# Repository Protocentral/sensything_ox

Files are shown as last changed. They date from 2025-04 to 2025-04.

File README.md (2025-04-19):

Protocentral Sensything Ox Wireless Pulse Sensor Kit based on AFE4400/ESP32S3
========================================
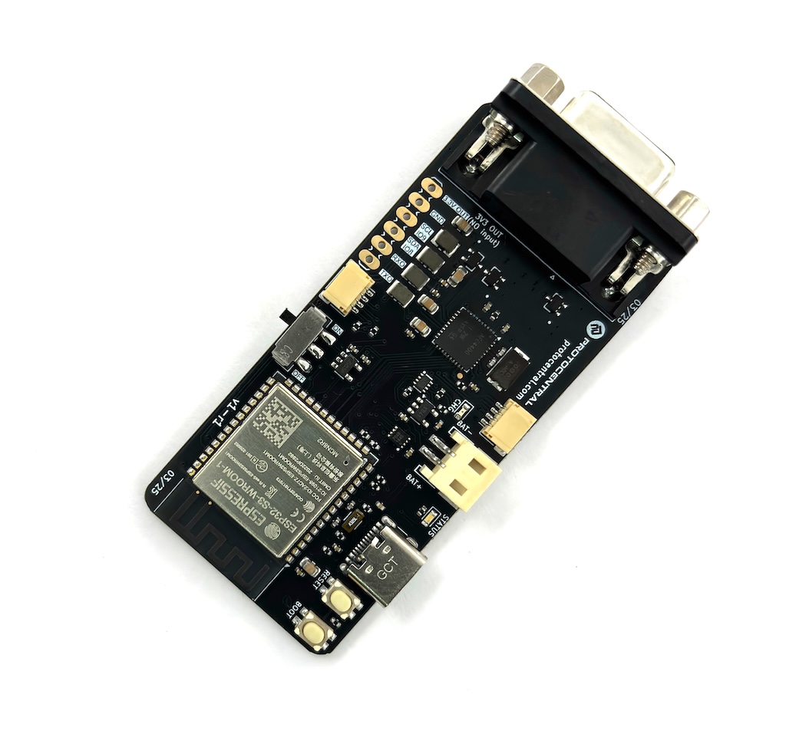
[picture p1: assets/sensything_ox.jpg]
Protocentral Sensything Ox Pulse Oximeter Breakout Board


## Don't have one? [Buy it here](https://protocentral.com/product/protocentral-sensythingox-wireless-pulse-sensor-kit-based-on-afe4400-esp32/)

Protocentral Sensything Ox is the latest, renamed version of our popular [OpenOx](https://github.com/Protocentral/protocentral_openox) Pulse sensor board. It is a standalone, wireless pulse oximetry breakout board that is powered by the ESP32S3 module and uses the AFE4400 IC to measure oxygen levels in the blood while also providing a PPG waveform, heart rate, and SpO2 values measured with high precision.

The Sensything Ox improves upon the previous version of the [OpenOx board](https://github.com/Protocentral/protocentral_openox) by replacing the ESP32 module with the new ESP32S3 with 8MB Flash memory and 2MB PSRAM. This allows for a more powerful and efficient processing of the data collected by the AFE4400 IC. The board is designed to be used in a variety of applications, including medical research, fitness tracking, and remote patient monitoring.

## Hardware Setup

The Sensything Ox programs are all in Arduino and examples are in the examples folder of this repo. To program, select the "ESP32S3 Dev Module" board in the Arduino IDE with the following settings.

* Board: ESP32S3 Dev Module
* USB Mode: Hardware CDC and JTAG
* USB CDC on Boot: Enabled
* Upload Mode: UART0 / Hardware CDC
* PSRAM: QSPI PSRAM

# Documentation

For further details of the board, refer the documentation at the following links:

[Protocentral Sensything Ox Wireless Pulse Sensor Documentation](https://docs.protocentral.com/getting-started-with-openox/)

# Visualizing Output

### USB Streaming

* Open the GUI, make sure to select **AFE4490 breakout** under the **Board** dropdown and the appropriate **Port**. If everything goes well, you will be able to see the screen as pictured above.

   <center>

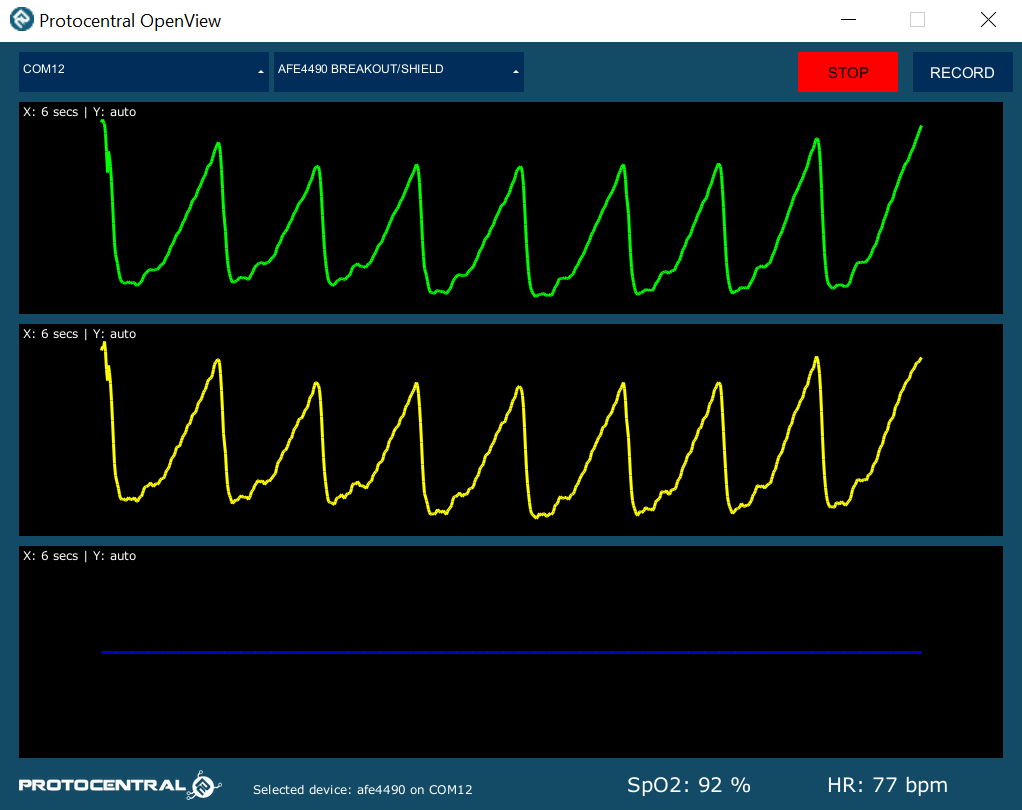
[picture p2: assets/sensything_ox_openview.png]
streaming vitals
  

  </center>

### BLE streaming

 <center>

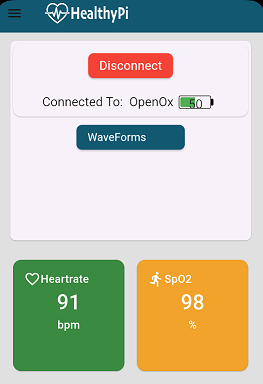
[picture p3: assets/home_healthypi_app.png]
Home
  

  </center>

 <center>

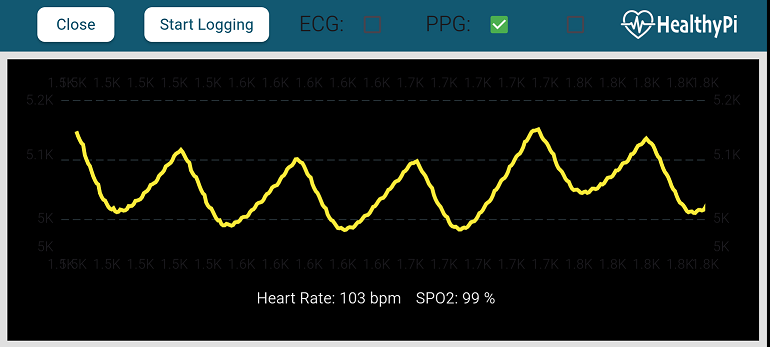
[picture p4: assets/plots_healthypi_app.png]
Plots
  

  </center>

License Information
===================

License

This product is open source! Both, our hardware and software are open source and licensed under the following licenses:

Hardware
---------

**All hardware is released under the [CERN-OHL-P v2](https://ohwr.org/cern_ohl_p_v2.txt)** license.

Copyright CERN 2020.

This source describes Open Hardware and is licensed under the CERN-OHL-P v2.

You may redistribute and modify this documentation and make products
using it under the terms of the CERN-OHL-P v2 (https:/cern.ch/cern-ohl).
This documentation is distributed WITHOUT ANY EXPRESS OR IMPLIED
WARRANTY, INCLUDING OF MERCHANTABILITY, SATISFACTORY QUALITY
AND FITNESS FOR A PARTICULAR PURPOSE. Please see the CERN-OHL-P v2
for applicable conditions

Software
--------

**All software is released under the MIT License(http://opensource.org/licenses/MIT).**

THE SOFTWARE IS PROVIDED "AS IS", WITHOUT WARRANTY OF ANY KIND, EXPRESS OR IMPLIED, INCLUDING BUT NOT LIMITED TO THE WARRANTIES OF MERCHANTABILITY, FITNESS FOR A PARTICULAR PURPOSE AND NONINFRINGEMENT. IN NO EVENT SHALL THE AUTHORS OR COPYRIGHT HOLDERS BE LIABLE FOR ANY CLAIM, DAMAGES OR OTHER LIABILITY, WHETHER IN AN ACTION OF CONTRACT, TORT OR OTHERWISE, ARISING FROM, OUT OF OR IN CONNECTION WITH THE SOFTWARE OR THE USE OR OTHER DEALINGS IN THE SOFTWARE.

Documentation
-------------
**All documentation is released under [Creative Commons Share-alike 4.0 International](http://creativecommons.org/licenses/by-sa/4.0/).**


You are free to:

* Share — copy and redistribute the material in any medium or format
* Adapt — remix, transform, and build upon the material for any purpose, even commercially.
The licensor cannot revoke these freedoms as long as you follow the license terms.

Under the following terms:

* Attribution — You must give appropriate credit, provide a link to the license, and indicate if changes were made. You may do so in any reasonable manner, but not in any way that suggests the licensor endorses you or your use.
* ShareAlike — If you remix, transform, or build upon the material, you must distribute your contributions under the same license as the original.

Please check [*LICENSE.md*](LICENSE.md) for detailed license descriptions.

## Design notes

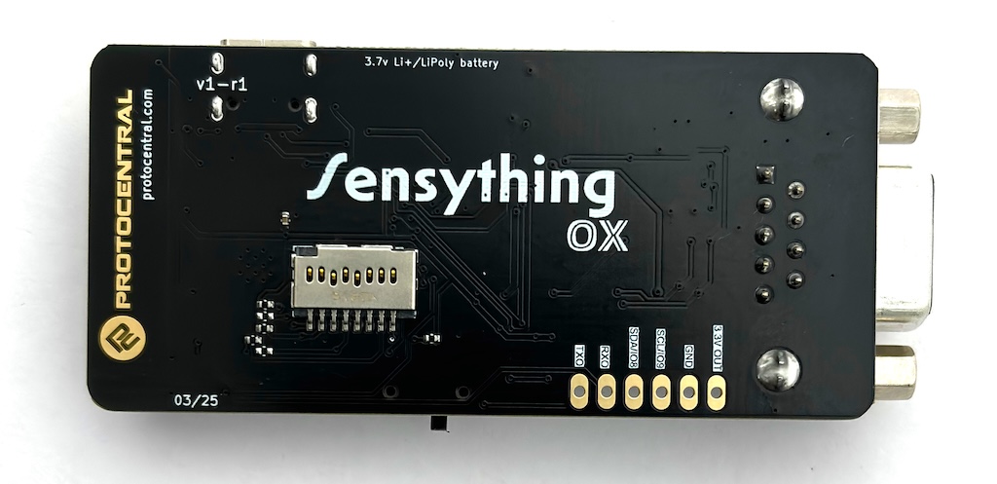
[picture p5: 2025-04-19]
assets/sensything_ox_back.jpg

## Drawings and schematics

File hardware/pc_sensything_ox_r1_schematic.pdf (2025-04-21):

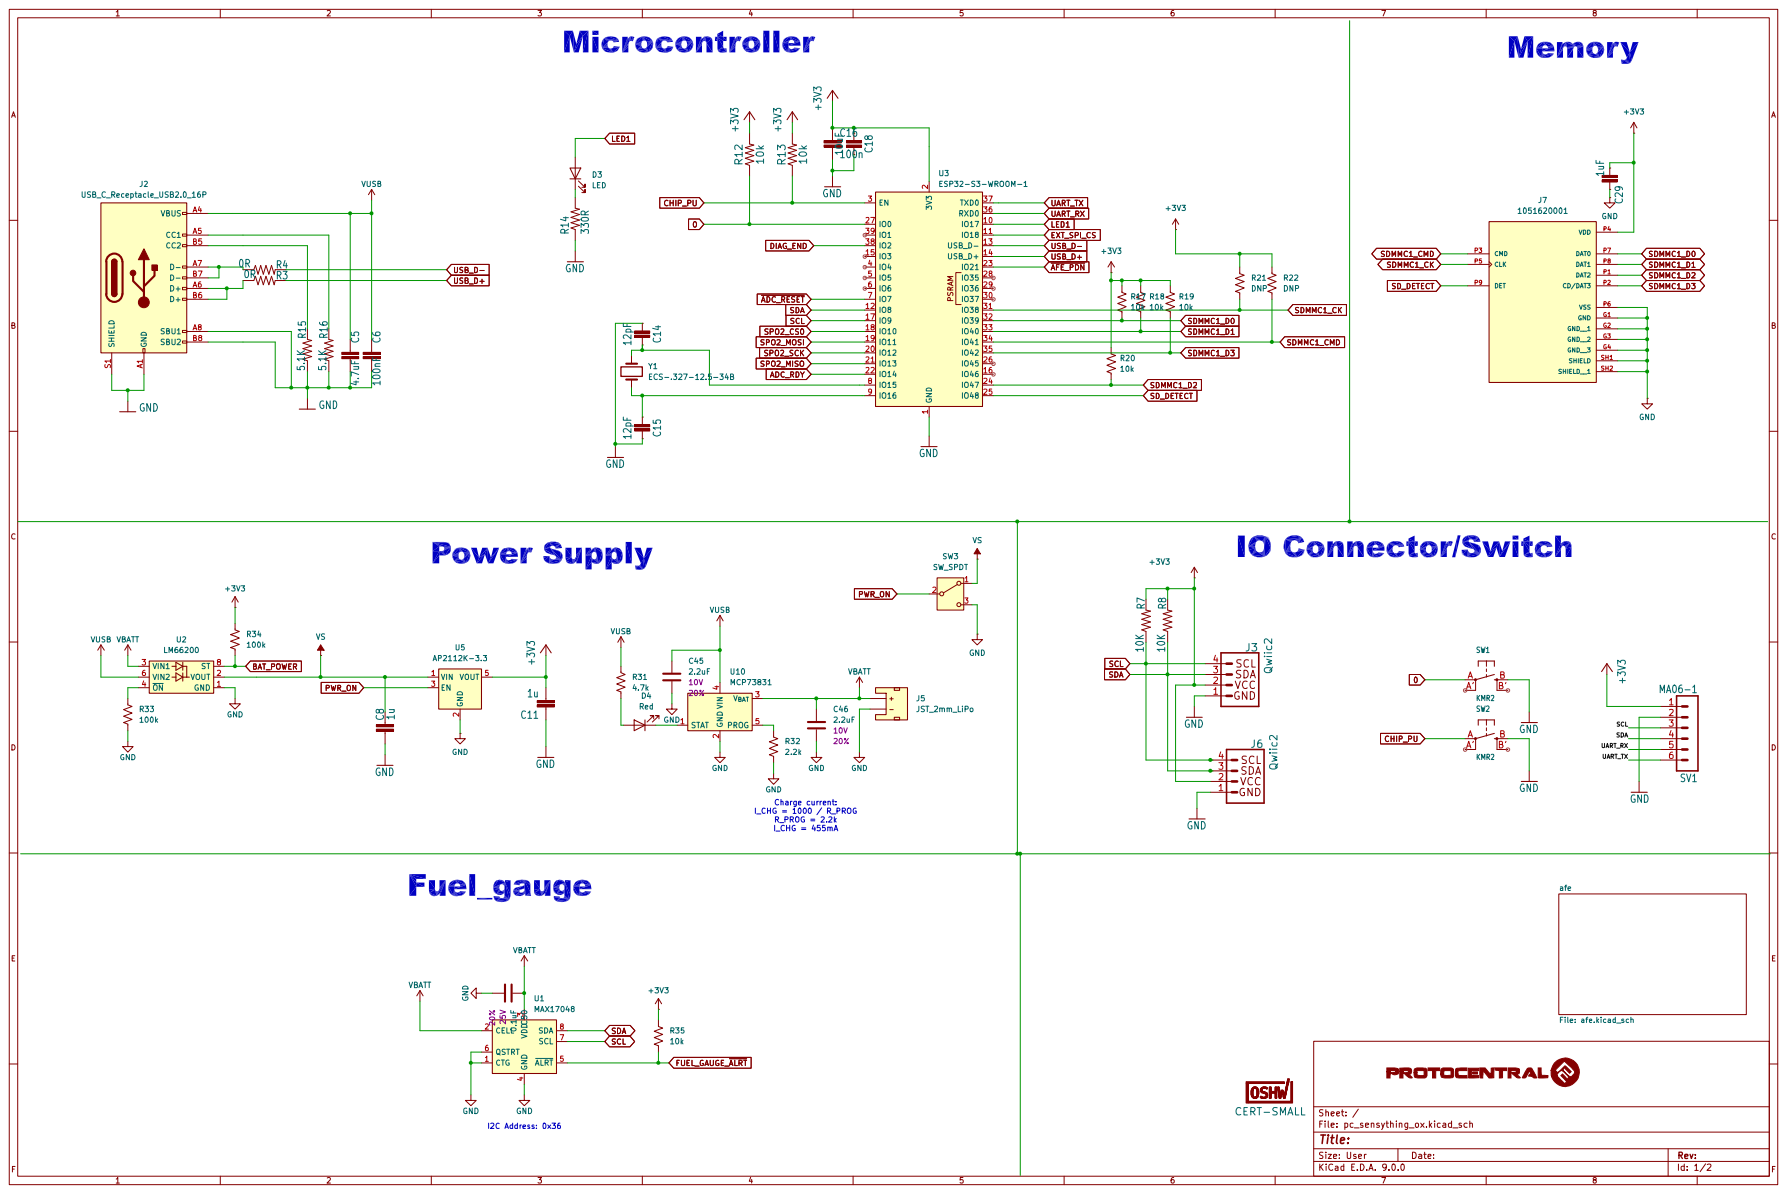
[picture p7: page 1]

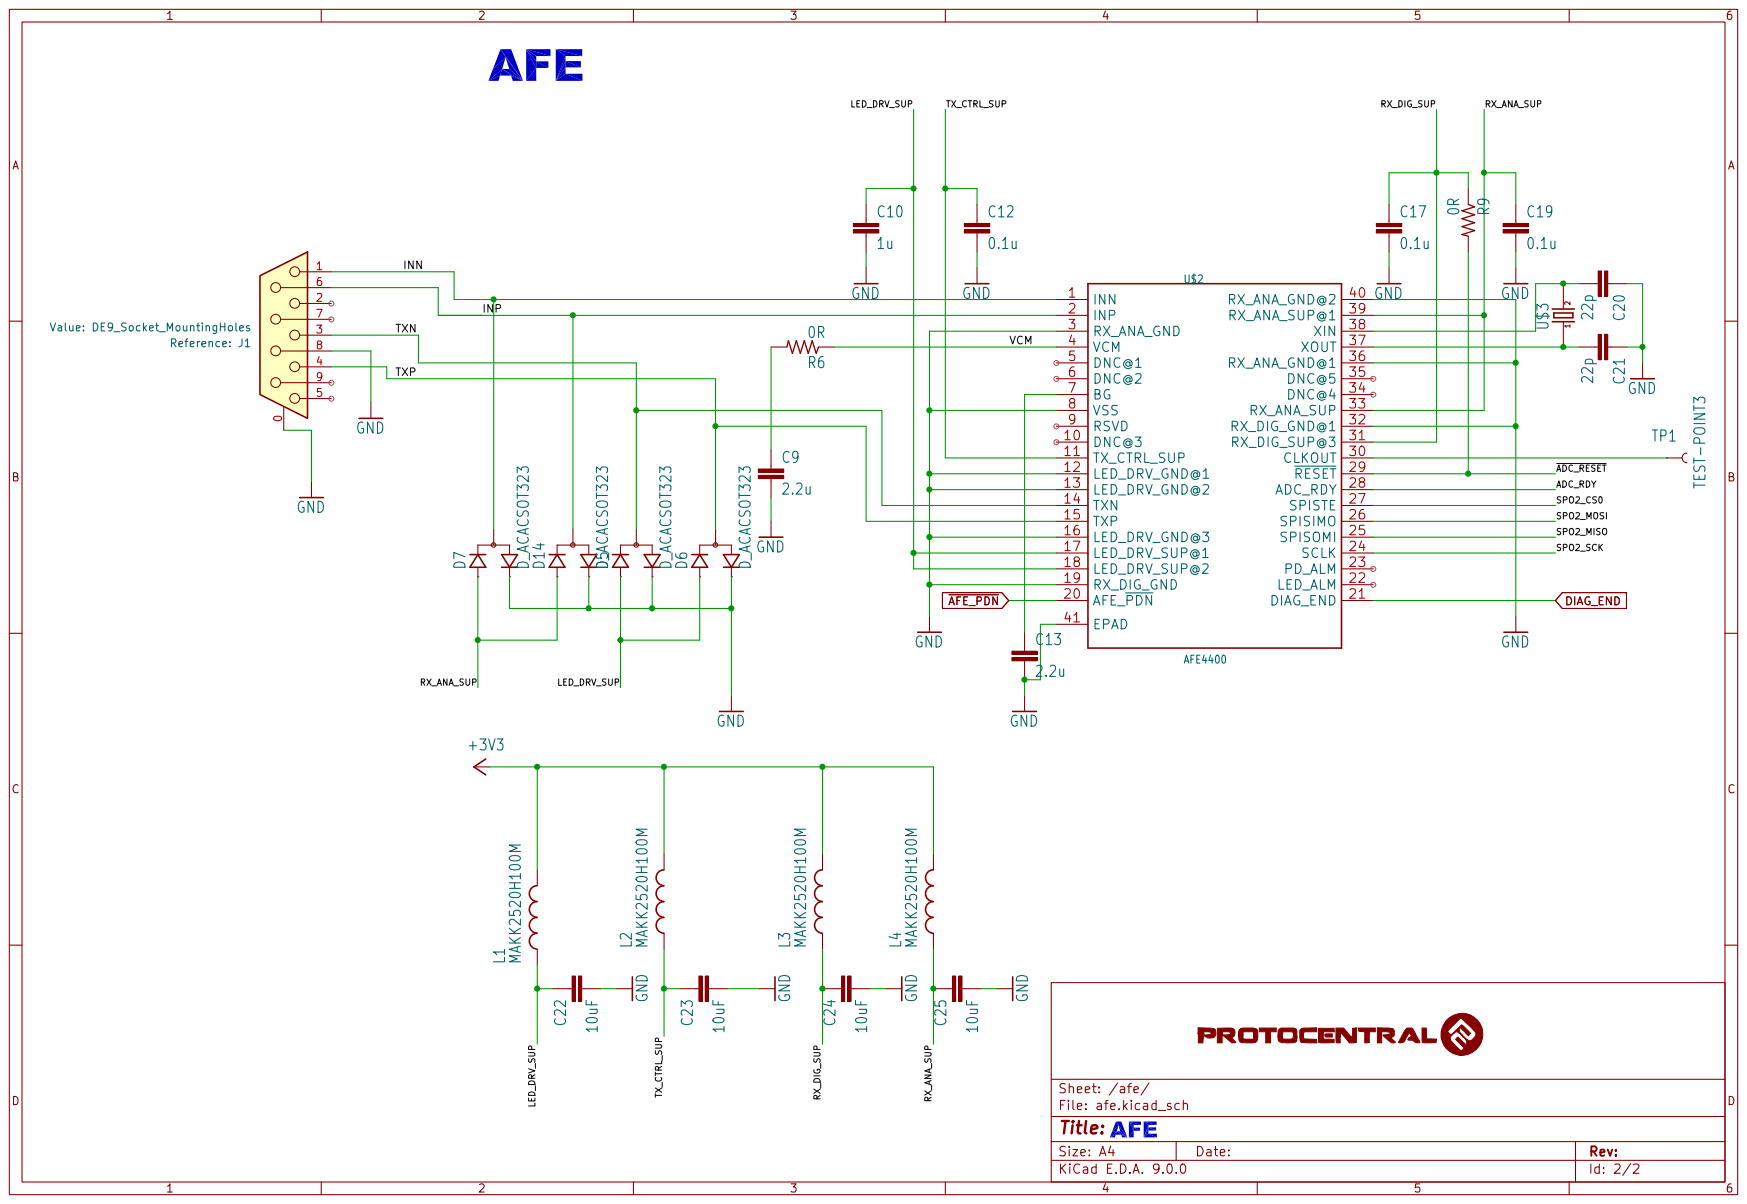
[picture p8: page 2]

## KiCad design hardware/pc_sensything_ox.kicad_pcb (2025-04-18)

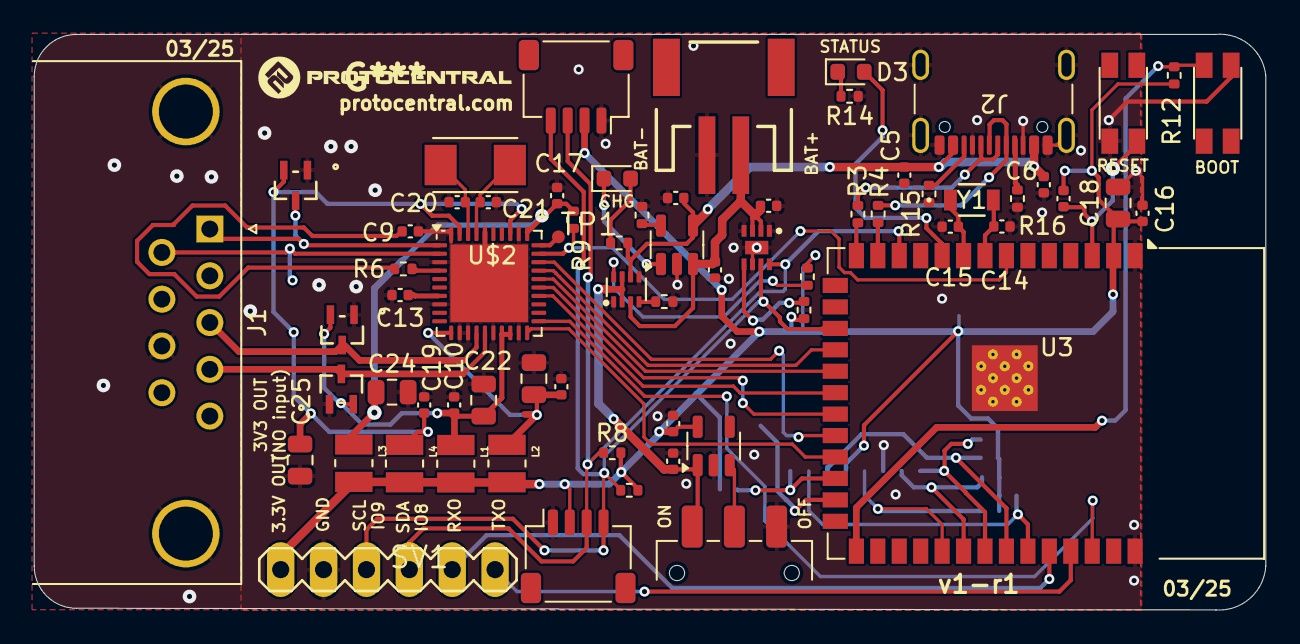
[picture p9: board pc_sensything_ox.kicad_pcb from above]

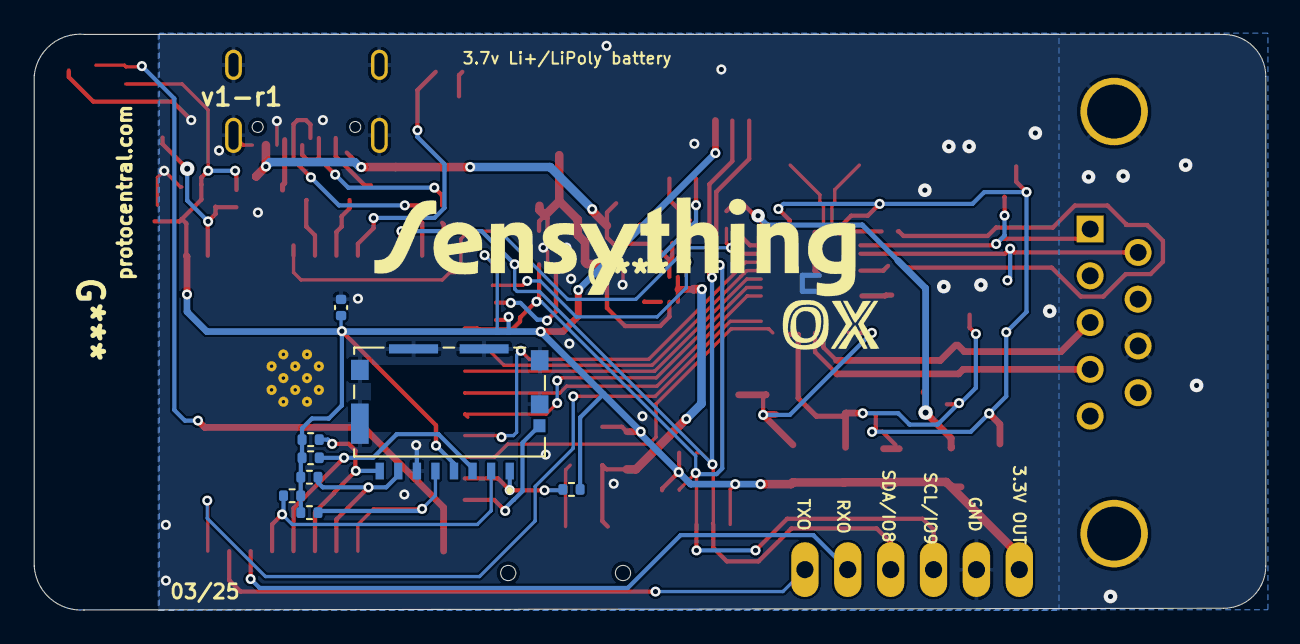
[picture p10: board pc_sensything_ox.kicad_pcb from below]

Board: 2 copper layers, 73.0 x 34.1 mm, 74 parts (8 on the bottom side), 57 nets.

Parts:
C5: 4.7uF; C_0402_1005Metric
C6: 100nF; C_0402_1005Metric
C8, C10, C11: 1u; C_0402_1005Metric
C9, C13: 2.2u; C_0402_1005Metric
C12, C17, C19: 0.1u; C_0402_1005Metric
C14, C15: 12pF; C_0402_1005Metric
C16: 100n; C_0402_1005Metric
C18, C22, C23, C24, C25: 10uF; C_0805_2012Metric
C20, C21: 22p; C_0402_1005Metric
C29: 1uF; C_0402_1005Metric
C45, C46: 2.2uF; C_0402_1005Metric
C50: 0.1uF; C_0402_1005Metric
D3: LED; LED_0603_1608Metric
D4: Red; LED_0603_1608Metric
D5, D6, D7: D_ACACSOT323; SOT-323_DIO
J1: DE9_Socket_MountingHoles; DSUB-9_Pins_Horizontal_P2.77x2.84mm_EdgePinOffset7.70mm_Hou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
J2: USB_C_Receptacle_USB2.0_16P; USB_C_Receptacle_GCT_USB4105-xx-A_16P_TopMnt_Horizontal
J3, J6: Qwiic2; JST_SH_SM04B-SRSS-TB_1x04-1MP_P1.00mm_Horizontal
J5: JST_2mm_LiPo; JST_SMD_2.0mm-2
J7: 1051620001; MOLEX_1051620001
L1, L2, L3, L4: MAKK2520H100M; INDC2520X100N
R3, R4, R6, R9: 0R; R_0402_1005Metric
R7, R8: 10K; R_0402_1005Metric
R12, R17, R18, R19, R20, R35: 10k; R_0402_1005Metric
R13: 10k; C_0402_1005Metric
R14: 330R; R_0402_1005Metric
R15, R16: 5.1K; R_0402_1005Metric
R21, R22: DNP; R_0402_1005Metric
R31: 4.7k; R_0402_1005Metric
R32: 2.2k; R_0402_1005Metric
R33, R34: 100k; R_0402_1005Metric
SV1: MA06-1
SW1, SW2: KMR2; BTN_KMR2_4.6X2.8
SW3: SW_SPDT; SW_SPDT_CK_JS102011SAQN
TP1: TEST-POINT3; PAD.03X.03
U1: MAX17048; DFN-8
U2: LM66200; SOT-583-8
U3: ESP32-S3-WROOM-1
U5: AP2112K-3.3; SOT-23-5
U10: MCP73831; SOT-23-5
U$2: AFE4400; Texas_RHA_VQFN-40-1EP_6x6mm_P0.5mm_EP4.6x4.6mm
U$3: ABM3; XTAL_ABM3-8.000MHZ-B4Y-T
Y1: ECS-.327-12.5-34B; XTAL_ECS-31B_ECS-L

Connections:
0: R12.1, SW1.A, U3.27 (IO0)
+3V3: C11.2, C16.1, C18.1, C29.1, J3.2, J6.2, J7.P4 (VDD), L1.2, L2.2, L3.2, L4.2, R7.2, R8.2, R12.2, R13.2, R17.1, R18.1, R19.1, R20.1, R21.1, R22.1, R34.1, R35.1, SV1.1, U3.2 (3V3), U5.5 (VOUT)
/INN: D7.1 (CA), J1.1, U$2.1 (INN)
/INP: J1.6, U$2.2 (INP)
/LED_DRV_SUP: C10.1, C22.1, D5.3 (A), D6.3 (A), L1.1, U$2.17 (LED_DRV_SUP@1), U$2.18 (LED_DRV_SUP@2)
/RX_ANA_SUP: C19.1, C25.1, D7.3 (A), L4.1, U$2.33 (RX_ANA_SUP), U$2.39 (RX_ANA_SUP@1)
/RX_DIG_SUP: C17.1, C24.1, L3.1, R9.1, U$2.31 (RX_DIG_SUP@3)
/TXP: D6.1 (CA), J1.4, U$2.15 (TXP)
/TX_CTRL_SUP: C12.1, C23.1, L2.1, U$2.11 (TX_CTRL_SUP)
/VCM: R6.1, U$2.4 (VCM)
ADC_RDY: U3.22 (IO14), U$2.28 (ADC_RDY)
BAT_POWER: R34.2, U2.8 (ST)
CHIP_PU: R13.1, SW2.A, U3.3 (EN)
DIAG_END: U3.38 (IO2), U$2.21 (DIAG_END)
FUEL_GAUGE_~ALRT: R35.2, U1.5 (~ALRT)
GND: C5.2, C6.2, C8.1, C9.2, C10.2, C11.1, C12.2, C13.2, C14.1, C15.2, C16.2, C17.2, C18.2, C19.2, C20.1, C21.1, C22.2, C23.2, C24.2, C25.2, C29.2, C45.2, C46.2, C50.2, D5.2 (C), D6.2 (C), D7.2 (C), J1.0 (PAD), J1.8, J2.A1 (GND), J2.A8 (SBU1), J2.A12 (GND), J2.B1 (GND), J2.B8 (SBU2), J2.B12 (GND), J2.S1 (SHIELD), J3.1, J5.1 (-), J6.1, J7.G1 (GND), J7.G2 (GND__1), J7.G3 (GND__2), J7.G4 (GND__3), J7.P6 (VSS), J7.SH1 (SHIELD), J7.SH2 (SHIELD__1), R14.1, R15.1, R16.1, R32.2, R33.2, SV1.2, SW1.B (S), SW2.B (S), SW3.3 (C), U1.1 (CTG), U1.4 (GND), U1.6 (QSTRT), U1.9 (GND), U2.1 (GND), U2.5 (GND), U3.1 (GND), U3.40 (GND), U3.41 (GND), U5.2 (GND), U10.2 (GND), U$2.3 (RX_ANA_GND), U$2.8 (VSS), U$2.12 (LED_DRV_GND@1), U$2.13 (LED_DRV_GND@2), U$2.16 (LED_DRV_GND@3), U$2.19 (RX_DIG_GND), U$2.32 (RX_DIG_GND@1), U$2.36 (RX_ANA_GND@1), U$2.40 (RX_ANA_GND@2), U$2.41 (EPAD)
LED1: D3.2 (A), U3.10 (IO17)
unnamed: C9.1, R6.2
unnamed: D3.1 (K), R14.2
unnamed: D4.2 (A), R31.2
unnamed: D4.1 (K), U10.1 (STAT)
unnamed: D5.1 (CA), J1.3, U$2.14 (TXN)
unnamed: J2.A5 (CC1), R16.2
unnamed: J2.B5 (CC2), R15.2
unnamed: J2.A6 (D+), J2.B6 (D+), R3.1
unnamed: J2.A7 (D-), J2.B7 (D-), R4.1
unnamed: TP1.P$1 (1), U$2.30 (CLKOUT)
unnamed: R33.1, U2.4 (~ON)
unnamed: C14.2, U3.8 (IO15), Y1.2
unnamed: C15.1, U3.9 (IO16), Y1.1
unnamed: R32.1, U10.5 (PROG)
unnamed: C13.1, U$2.7 (BG)
unnamed: C20.2, U$2.38 (XIN), U$3.2
unnamed: C21.2, U$2.37 (XOUT), U$3.1
PWR_ON: SW3.2 (B), U5.3 (EN)
SCL: J3.4, J6.4, R7.1, SV1.3, U1.7 (SCL), U3.17 (IO9)
SDA: J3.3, J6.3, R8.1, SV1.4, U1.8 (SDA), U3.12 (IO8)
SDMMC1_CK: J7.P5 (CLK), R21.2, U3.31 (IO38)
SDMMC1_CMD: J7.P3 (CMD), R22.2, U3.34 (IO41)
SDMMC1_D0: J7.P7 (DAT0), R17.2, U3.32 (IO39)
SDMMC1_D1: J7.P8 (DAT1), R18.2, U3.33 (IO40)
SDMMC1_D2: J7.P1 (DAT2), R20.2, U3.24 (IO47)
SDMMC1_D3: J7.P2 (CD/DAT3), R19.2, U3.35 (IO42)
SD_DETECT: J7.P9 (DET), U3.25 (IO48)
SPO2_CS0: U3.18 (IO10), U$2.27 (SPISTE)
SPO2_MISO: U3.21 (IO13), U$2.25 (SPISOMI)
SPO2_MOSI: U3.19 (IO11), U$2.26 (SPISIMO)
SPO2_SCK: U3.20 (IO12), U$2.24 (SCLK)
UART_RX: SV1.5, U3.36 (RXD0)
UART_TX: SV1.6, U3.37 (TXD0)
USB_D+: R3.2, U3.14 (USB_D+)
USB_D-: R4.2, U3.13 (USB_D-)
VBATT: C46.1, C50.1, J5.2 (+), U1.2 (CELL), U1.3 (VDD), U2.3 (VIN1), U10.3 (V_{BAT})
VS: C8.2, SW3.1 (A), U2.2 (VOUT), U2.7 (VOUT), U5.1 (VIN)
VUSB: C5.1, C6.1, C45.1, J2.A4 (VBUS), J2.A9 (VBUS), J2.B4 (VBUS), J2.B9 (VBUS), R31.1, U2.6 (VIN2), U10.4 (VIN)
~ADC_RESET: R9.2, U3.7 (IO7), U$2.29 (~RESET)
~AFE_PDN: U3.23 (IO21), U$2.20 (AFE_~PDN)

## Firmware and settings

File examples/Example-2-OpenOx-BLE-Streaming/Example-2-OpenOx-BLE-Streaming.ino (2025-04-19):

//////////////////////////////////////////////////////////////////////////////////////////
//    Protocentral Electronics 2025
//    
//    This example is for the Protocentral Sensything Ox Pulse Sensor
//
//    This software is licensed under the MIT License(http://opensource.org/licenses/MIT).
//
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
/////////////////////////////////////////////////////////////////////////////////////////

#include <SPI.h>
#include <protocentral_afe44xx.h>

#include <BLEDevice.h>
#include <BLEServer.h>
#include <BLEUtils.h>
#include <BLE2902.h>

#define AFE44XX_CS_PIN 10
#define AFE44XX_DRDY_PIN 14
#define AFE44XX_PWDN_PIN 21

#define Heartrate_SERVICE_UUID (uint16_t(0x180D))
#define Heartrate_CHARACTERISTIC_UUID (uint16_t(0x2A37))
#define sp02_SERVICE_UUID (uint16_t(0x1822))
#define sp02_CHARACTERISTIC_UUID (uint16_t(0x2A5E))
#define HRV_SERVICE_UUID "cd5c7491-4448-7db8-ae4c-d1da8cba36d0"
#define HIST_CHARACTERISTIC_UUID "cd5c1525-4448-7db8-ae4c-d1da8cba36d0"
#define DATASTREAM_SERVICE_UUID (uint16_t(0x1122))
#define DATASTREAM_CHARACTERISTIC_UUID (uint16_t(0x1424))

AFE44XX afe44xx(AFE44XX_CS_PIN, AFE44XX_PWDN_PIN);

afe44xx_data afe44xx_raw_data;
uint8_t ppg_data_buff[20];
int16_t ppg_wave_ir;
uint16_t ppg_stream_cnt = 0;
uint8_t sp02;
uint8_t heartrate;
bool ppg_buf_ready = false;
bool spo2_calc_done = false;
bool heartrate_calc_done = false;
bool deviceConnected = false;
bool oldDeviceConnected = false;

String strValue = "";

BLEServer *pServer = NULL;
BLECharacteristic *Heartrate_Characteristic = NULL;
BLECharacteristic *sp02_Characteristic = NULL;
BLECharacteristic *hist_Characteristic = NULL;
BLECharacteristic *hrv_Characteristic = NULL;
BLECharacteristic *datastream_Characteristic = NULL;

class MyServerCallbacks : public BLEServerCallbacks
{
  void onConnect(BLEServer *pServer)
  {
    deviceConnected = true;
    Serial.println("connected");
  }

  void onDisconnect(BLEServer *pServer)
  {
    deviceConnected = false;
    Serial.println("disconnected");
  }
};

class MyCallbackHandler : public BLECharacteristicCallbacks
{
  void onWrite(BLECharacteristic *datastream_Characteristic)
  {
    std::string value = datastream_Characteristic->getValue();
    int len = value.length();
    strValue = "0";

    if (value.length() > 0)
    {
      Serial.print("New value: ");

      for (int i = 0; i < value.length(); i++)
      {
        Serial.print(String(value[i]));
        strValue += value[i];
      }

      Serial.println();
    }
  }
};

void OpenOx_BLE_Init()
{
  BLEDevice::init("OpenOx");           // Create the BLE Device
  pServer = BLEDevice::createServer(); // Create the BLE Server
  pServer->setCallbacks(new MyServerCallbacks());
  BLEService *HeartrateService = pServer->createService(Heartrate_SERVICE_UUID); // Create the BLE Service
  BLEService *sp02Service = pServer->createService(sp02_SERVICE_UUID);           // Create the BLE Service
  BLEService *hrvService = pServer->createService(HRV_SERVICE_UUID);
  BLEService *datastreamService = pServer->createService(DATASTREAM_SERVICE_UUID);

  Heartrate_Characteristic = HeartrateService->createCharacteristic(
      Heartrate_CHARACTERISTIC_UUID,
      BLECharacteristic::PROPERTY_READ |
          BLECharacteristic::PROPERTY_WRITE |
          BLECharacteristic::PROPERTY_NOTIFY);

  sp02_Characteristic = sp02Service->createCharacteristic(
      sp02_CHARACTERISTIC_UUID,
      BLECharacteristic::PROPERTY_READ |
          BLECharacteristic::PROPERTY_WRITE |
          BLECharacteristic::PROPERTY_NOTIFY);

  hist_Characteristic = hrvService->createCharacteristic(
      HIST_CHARACTERISTIC_UUID,
      BLECharacteristic::PROPERTY_READ |
          BLECharacteristic::PROPERTY_WRITE |
          BLECharacteristic::PROPERTY_NOTIFY);

  datastream_Characteristic = datastreamService->createCharacteristic(
      DATASTREAM_CHARACTERISTIC_UUID,
      BLECharacteristic::PROPERTY_READ |
          BLECharacteristic::PROPERTY_WRITE |
          BLECharacteristic::PROPERTY_NOTIFY);

  Heartrate_Characteristic->addDescriptor(new BLE2902());
  sp02_Characteristic->addDescriptor(new BLE2902());
  hist_Characteristic->addDescriptor(new BLE2902());
  datastream_Characteristic->addDescriptor(new BLE2902());
  datastream_Characteristic->setCallbacks(new MyCallbackHandler());

  // Start the service
  HeartrateService->start();
  sp02Service->start();
  hrvService->start();
  datastreamService->start();

  // Start advertising
  BLEAdvertising *pAdvertising = BLEDevice::getAdvertising();
  pAdvertising->addServiceUUID(Heartrate_SERVICE_UUID);
  pAdvertising->addServiceUUID(sp02_SERVICE_UUID);
  pAdvertising->addServiceUUID(HRV_SERVICE_UUID);
  pAdvertising->addServiceUUID(DATASTREAM_SERVICE_UUID);
  pAdvertising->setScanResponse(false);
  pAdvertising->setMinPreferred(0x00); // set value to 0x00 to not advertise this parameter
  BLEDevice::startAdvertising();
  Serial.println("Waiting a client connection to notify...");
}

void handle_ble_stack()
{

  if (ppg_buf_ready)
  {
    ppg_buf_ready = false;
    hist_Characteristic->setValue(ppg_data_buff, 19);
    hist_Characteristic->notify();
  }

  if (spo2_calc_done)
  {
    // afe44xx_raw_data.buffer_count_overflow = false;
    uint8_t spo2_att_ble[5];
    spo2_att_ble[0] = 0x00;
    spo2_att_ble[1] = (uint8_t)sp02;
    spo2_att_ble[2] = (uint8_t)(sp02 >> 8);
    spo2_att_ble[3] = (uint8_t)heartrate;
    ;
    spo2_att_ble[4] = (uint8_t)(heartrate >> 8);
    sp02_Characteristic->setValue(spo2_att_ble, 5);
    sp02_Characteristic->notify();
    spo2_calc_done = false;
  }

  if (heartrate_calc_done)
  {
    // afe44xx_raw_data.buffer_count_overflow = false;
    uint8_t heartrate_att_ble[5];
    heartrate_att_ble[0] = 0x00;
    heartrate_att_ble[1] = (uint8_t)heartrate;
    heartrate_att_ble[2] = (uint8_t)(heartrate >> 8);
    Heartrate_Characteristic->setValue(heartrate_att_ble, 3);
    Heartrate_Characteristic->notify();
    heartrate_calc_done = false;
  }

  if (!deviceConnected && oldDeviceConnected)
  {
    delay(500);                  // give the bluetooth stack the chance to get things ready
    pServer->startAdvertising(); // restart advertising
    Serial.println("start advertising");
    oldDeviceConnected = deviceConnected;
  }

  // connecting
  if (deviceConnected && !oldDeviceConnected)
  {
    // do stuff here on connecting
    oldDeviceConnected = deviceConnected;
  }
}

void setup()
{
  Serial.begin(57600);
  Serial.println("Intilaziting AFE44xx.. ");
  delay(2000); // pause for a moment

  OpenOx_BLE_Init();
  SPI.begin();

  afe44xx.afe44xx_init();
  Serial.println("Inited...");
}

void loop()
{
  delay(8);

  afe44xx.get_AFE44XX_Data(&afe44xx_raw_data);
  ppg_wave_ir = (int16_t)(afe44xx_raw_data.IR_data >> 8);
  ppg_wave_ir = ppg_wave_ir;

  ppg_data_buff[ppg_stream_cnt++] = (uint8_t)ppg_wave_ir;
  ppg_data_buff[ppg_stream_cnt++] = (ppg_wave_ir >> 8);

  if (ppg_stream_cnt >= 19)
  {
    ppg_buf_ready = true;
    ppg_stream_cnt = 0;
  }

  if (afe44xx_raw_data.buffer_count_overflow)
  {

    if (afe44xx_raw_data.spo2 == -999)
    {
      sp02 = 0;
      heartrate = 0;
    }
    else
    {
      sp02 = (uint8_t)afe44xx_raw_data.spo2;
      spo2_calc_done = true;
      heartrate = (uint8_t)afe44xx_raw_data.heart_rate;
      heartrate_calc_done = true;
    }

    afe44xx_raw_data.buffer_count_overflow = false;
  }
  handle_ble_stack();
}

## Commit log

2025-04-19 Updated Sensything Ox board
2025-04-21 For update
    [pc_sensything_ox.kicad_pcb, pc_sensything_ox.kicad_sch]

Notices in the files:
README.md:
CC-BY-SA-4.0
